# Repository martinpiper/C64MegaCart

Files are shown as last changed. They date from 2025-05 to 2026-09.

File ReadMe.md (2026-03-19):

# C64 Open source cartridges and programmers

## C64MegaCart V4.3

* 2 Megabyte of Flash memory
* Flash can be erased, either the whole memroy or smaller banks, and written by the C64
* When ordering 100 units, each unit should cost about USD 10, excluding shipping and import taxes.
* Can be ordered direct from PCBWay: https://www.pcbway.com/project/shareproject/Commodore_64_MegaCart_V4_3_2MB_eafeb0e4.html
* Code that demonstrates erase and write of a cartridge with some example boot code: https://github.com/martinpiper/C64MegaCart/blob/main/WriteCartTest.a
* Code that demonstrates flash memory erase and write, with cartridge bank kill functionality: https://github.com/martinpiper/C64MegaCart/blob/main/FlashWriteTest.a
* Assembled prg files for this example code are also in this repository.
* Source code for the stdlib includes can be found in this repository: https://github.com/martinpiper/C64Public/tree/master/stdlib

## Cartridge programmer tool

* This is a Raspberry Pi hat
* Software running on the Raspberry Pi can erase, write, and read the flash memory
* Setup video: https://www.youtube.com/watch?v=GBg5k46B5Pw
* Setup instructions: https://github.com/martinpiper/C64MegaCart/blob/main/PiCartTool/ReadMe.md#setup-software-using-gcc
* It multiplexes signals to increase the number of inputs and outputs, allowing the full range of Commodore 64 expansion port signals to be controlled
* It uses MOSFETs to drive higher currents at higher frequencies
* Can be ordered direct from PCBWay: https://www.pcbway.com/project/shareproject/C64_Cartridge_programming_tool_V2_4b4c9cff.html
* Raspberry Pi source code for the programmer is here: https://github.com/martinpiper/C64MegaCart/tree/main/PiCartTool

## About PCB assembly costs

PCBWay have fixed assembly and fabrication setup fees, so when ordering a small number of units these fees increase per unit cost. The best way to reduce the impact of setup fees is to order more units, in bulk.

## Cartridge case for normal sized PCBs

* Case assembly video: https://www.youtube.com/watch?v=x988wTCP7Js
* C64MegaCartNormalCase.FCStd
* Can be used with: FreeCAD_1.0.2-conda-Windows-x86_64-py311
* Top part: https://www.pcbway.com/project/shareproject/Commodore_64_MegaCart_case_Top_f965217a.html
* Bottom part: https://www.pcbway.com/project/shareproject/Commodore_64_MegaCart_case_Bottom_1492af35.html

## Vice 3.1 support

* Vice 3.1 Win32 DirectX build with C64MegaCart support: https://github.com/martinpiper/Vice-3.1-with-C64MegaCart/tree/main/vice-3.1/data
* There are many hooks for the cartridge system, the main source is in: https://github.com/martinpiper/Vice-3.1-with-C64MegaCart/blob/main/vice-3.1/src/c64/cart/c64megacart.c

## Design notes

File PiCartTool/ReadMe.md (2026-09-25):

## Command line arguments

	Long form								Short form	Documentation
	--waitbutton							-b			Waits for the button on the programmer board to be pressed
	--erase									-e			Erases the whole flash memory, first chip only
	--eraseserial							-es			Erases the whole serial EEPROM memory
	--erasechips <num chips>				-ec			Erases the whole flash memory for the number of chips, in parallel
	--eraseblock <number>					-eb			Erases one block of the flash memory using the number value to choose which block. Each flash chip has 256 blocks (banks)
														This depends on the geometry of the flash memory. For example for the chip M29F160FT55N3E2, using 253 will erase the 8KB block at 0x1fa000
	--write <filename>						-w			Writes the file to the flash memory
	--writeserial <filename>				-ws			Writes the file to the serial EEPROM memory
	--writebyte <address> <byte>			-wb			Write a single byte to the address.
	--read <num banks> <filename>			-r			Reads the whole cartridge for the number of banks and writes the data to the filename as a binary file. Only the first slot.
	--readserial <filename>					-rs			Reads the whole serial EEPROM and writes the data to the filename as a binary file. Only the first slot.
	--loop									-l			Loops back to the start of the command line arguments
	--dump <address> <num bytes>			-d			Dumps the flash memory from address for the number of bytes
	--dumpserial <address> <num bytes>		-ds			Dumps the serial EEPROM memory from address for the number of bytes
	--slots <num>							-s			The nunber of slots being used, default is 1, from the front slot to the rear slot

For example, to repeatedly erase and write a file to the cartridge while waiting for the button to be pressed before each erase/write pass:

	--waitbutton --erase --write scrollerbanks.bin --loop

Or for example, to read data from a 256 bank cartridge to a file:

	--read 256 readdata.bin

Or to dump 15 bytes from 0x1fa000, erase the whole block, dump the same bytes to show they are erased, then write a single byte to 0x1fa007, and then dump the bytes to show the single updated byte:

	--dump 0x1fa000 0xf --eraseblock 253 --dump 0x1fa000 0xf  --writebyte 0x1fa007 0x56  --dump 0x1fa000 0xf

## Minimal cartridge boot test

The file CartBoot.bin (assembled from C64MegaCart\CartBoot.a) is a very small minimal cartridge boot which will show a message

	--erase --write CartBoot.bin
	
## Cartridge run EEPROM tester

The file CartBootSimplePRG.bin (assembled from C64MegaCart\CartBootSimplePRG.a) will automatically run an EEPROM tester

	--erase --write CartBootSimplePRG.bin

## Errors

If all LEDs rapidly flash on and off this means there was an error. Usually this happens during erase or write.
The tool will wait for a button to be pressed before executing the next command in the command line.

## Cartridge types

Different cartridges have different requirements for how to write the flash.
C64MegaCart is the default option for this cart tool, so these advanced options are not required, however other cartridges can be configured.
The advanced configuration command line options must be used before the cartridge is accessed.

| Type			| Command line options					| Size (megabytes)	| Typical time to erase and write	|
| ---			| ---									| ---				| ---								|
| 			| 									| 				| Raspberry Pi 5					|
| C64MegaCart	| None needed, use default config		| 2					| 62 seconds						|
| Megabyter		| --cfwcl --cfwdci 4 --crdms 1 --cfwec	| 1					| 44 seconds						|
| Gmod2			| --cfwec --cfct 1						| 0.5 + 2KB EEPROM	| 20 seconds						|
| 			| 									| 				| Raspberry Pi Zero 2W				|
| C64MegaCart	| None needed, use default config		| 2					| 99 seconds						|

Default options are: --cfwch --cfwdci 0 --crdms 0 --cfwnec

### Advanced configuration options

These options alter the timings and other signals expected by different cartridges types.

	Long form			Documentation
	--cfwch				HIROM is used to write to the cartridge flash
	--cfwcl				LOROM is used to write to the cartridge flash
	--cfwdci <number>	Number of times the dot clock signal is toggled during IO/read/write phases
	--crdms <number>	Delay in microseconds
	--cfwec				Use extra clocking for signal generation. This is closer to the standard C64 signal timing, but is slower.
	--cfwnec			No extra clocking for signal generation. This option if faster but some cartridges are unable tolerate the non-standard timings.
	--cfct <number>		0 = M29F160, 1 = M29F040

## Setup software using gcc

Video showing the whole process: https://youtu.be/GBg5k46B5Pw

Video showing the five slot programmer: https://youtu.be/I6Ru7vbInTw

This software uses: https://github.com/WiringPi/WiringPi

	sudo apt install git
	git clone https://github.com/WiringPi/WiringPi.git

Or if that repository disappears:

	git clone https://github.com/martinpiper/WiringPi.git

Then compile with:

	cd WiringPi
	./build
	cd ..

To compile the programmer tool:

	git clone https://github.com/martinpiper/C64MegaCart.git
	cd C64MegaCart/PiCartTool
	gcc main.cpp Hardware.cpp CartridgePort.cpp ProgrammerHardware.cpp CartridgeHardware.cpp -o PiCartTool -lstdc++ -lwiringPi -O3

You can then use this command to test erase and write the cartridge:

	./PiCartTool --waitbutton --erase --write scrollerbanks.bin --loop

## Setup software using Microsoft Dev Studio

Usually gcc builds will work fine, this is more for remote development and debugging.

MSDev->Tools->Options->Cross Platform->Connection Manager
Default Raspberry Pi login: user:pi password:raspberry
Configuration Manager: ARM64

	cd ~/projects/PiCartTool/bin/ARM64/Release/
	time ./PiCartTool.out --erase --write ../../../scrollerbanks.bin
	diff -q ../../../scrollerbanks.bin ../../../readdata.bin
	cmp -l ../../../scrollerbanks.bin ../../../readdata.bin | mawk 'function oct2dec(oct,     dec) {for (i = 1; i <= length(oct); i++) {dec *= 8; dec += substr(oct, i, 1)}; return dec} {printf "%08X %02X %02X\n", $1-1, oct2dec($2), oct2dec($3)}'

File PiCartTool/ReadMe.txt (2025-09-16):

## Command line arguments

	Long form				Short form	Documentation
	--waitbutton			-b			Waits for the button on the programmer board to be presse
	--erase					-e			Erases the whole flash memor
	--eraseblock <number>	-eb			Erases one block of the flash memory using the number value to choose which block.
										This depends on the geometry of the flash memory. For example for the chip M29F160FT55N3E2, using 253 will erase the 8KB block at $1fa000.
	--write <filename>		-w			Writes the file to the flash memor
	--read <filename>		-r			Reads the whole cartridge and writes the data to the filename as a binary fil
	--loop					-l			Loops back to the start of the command line arguments

For example, to repeatedly erase and write a file to the cartridge while waiting for the button to be poressed before each erase/write pass:

	--waitbutton --erase --write scrollerbanks.bin --loop

## Setup software using gcc

This uses: https://github.com/WiringPi/WiringPi

sudo apt install git
git clone https://github.com/WiringPi/WiringPi.git
Or if that repository disappears: git clone https://github.com/martinpiper/WiringPi.git
cd WiringPi
./build
cd ..

git clone https://github.com/martinpiper/C64MegaCart.git
cd C64MegaCart/PiCartTool
gcc main.cpp -o PiCartTool -lwiringPi -O3

You can then use this command to test erase and write the cartridge: ./PiCartTool --waitbutton --erase --write scrollerbanks.bin --loop

## Setup software using Microsoft Dev Studio

Usually gcc builds will work fine, this is more for remote development and debugging.

MSDev->Tools->Options->Cross Platform->Connection Manager
Default Raspberry Pi login: user:pi password:raspberry

cd ~/projects/PiCartTool/bin/ARM/Release/
time ./PiCartTool.out
diff -q ../../../scrollerbanks.bin ../../../readdata.bin
cmp -l ../../../scrollerbanks.bin ../../../readdata.bin | mawk 'function oct2dec(oct,     dec) {for (i = 1; i <= length(oct); i++) {dec *= 8; dec += substr(oct, i, 1)}; return dec} {printf "%08X %02X %02X\n", $1-1, oct2dec($2), oct2dec($3)}'

RaspberryPi5 erase 2MB + write 2MB + read/verify 2MB cycle = 1m17s
The PiZero took about 2m for the same erase/write
The full read/verify on its own takes 17s
It's probably not needed since the write uses a read to verify the write has completed.

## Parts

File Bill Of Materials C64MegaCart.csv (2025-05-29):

Category | Quantity | References | Value | Stock Code | Description | Group Layer | PCB Package | Placed
Capacitors | 1 | C1 | CL05B104KO5NNNC | https://www.mouser.sg/ProductDetail/Samsung-Electro-Mechanics/CL05B104KO5NNNC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 | Samsung Electro-Mechanics CL05B104KO5NNNC 100nF Multilayer Ceramic Capacitor MLCC 16V dc +/-10% Tolerance SMD |  | CAPC1005X55N | Top Copper
Integrated Circuits | 1 | U1 | M29F160FT55N3E2 | https://www.mouser.sg/ProductDetail/Alliance-Memory/M29F160FT55N3E2?qs=vmHwEFxEFR%252BPKObcaS0Aqw%3D%3D | NOR Flash |  | SOP50P2000X120-48N | Top Copper
Integrated Circuits | 1 | U259 | 74273 | https://www.mouser.sg/ProductDetail/Texas-Instruments/SN74LS273NSR?qs=SL3LIuy2dWxsq%2FCTeVMKZg%3D%3D | Octal D-Type Positive-Edge-Triggered Flip-Flops With Clear | Video | SOIC127P780X200-20N-CAP | Top Copper
Miscellaneous | 1 | 7R | 74S139 | https://www.mouser.sg/ProductDetail/Texas-Instruments/SN74LS139ADR?qs=SL3LIuy2dWwpYzaAOf%252BnlA%3D%3D | Dual 2-Line to 4-Line Decoders/Demultiplexers | Video | SOIC127P600X175-16N-CAP | Top Copper

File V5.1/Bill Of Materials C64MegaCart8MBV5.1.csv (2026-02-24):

Category | Quantity | References | Value | Stock Code | Description | Group Layer | PCB Package | Supplier | Placed
Capacitors | 4 | C1,C2,C3,C4 | CL05B104KO5NNNC | https://www.mouser.sg/ProductDetail/Samsung-Electro-Mechanics/CL05B104KO5NNNC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 | Samsung Electro-Mechanics CL05B104KO5NNNC 100nF Multilayer Ceramic Capacitor MLCC 16V dc +/-10% Tolerance SMD |  | CAPC1005X55N |  | Top Copper
Integrated Circuits | 4 | U1,U6,U7,U8 | M29F160FT55N3E2 | https://www.mouser.sg/ProductDetail/Alliance-Memory/M29F160FT55N3E2?qs=vmHwEFxEFR%252BPKObcaS0Aqw%3D%3D | NOR Flash |  | SOP50P2000X120-48N |  | Top Copper
Integrated Circuits | 2 | U2,U3 | 74273 | https://www.mouser.sg/ProductDetail/Texas-Instruments/SN74LS273NSR?qs=SL3LIuy2dWxsq%2FCTeVMKZg%3D%3D | Octal D-Type Positive-Edge-Triggered Flip-Flops With Clear |  | SOIC127P780X200-20N-CAP | https://www.mouser.sg/ProductDetail/Mill-Max/110-43-320-41-801000?qs=RC2ne4458IKe5rHuueYA%2FA%3D%3D | Top Copper
Integrated Circuits | 3 | U4,U5,U9 | 74S139 | https://www.mouser.sg/ProductDetail/Texas-Instruments/SN74LS139ADR?qs=SL3LIuy2dWwpYzaAOf%252BnlA%3D%3D | Dual 2-Line to 4-Line Decoders/Demultiplexers |  | SOIC127P600X175-16N-CAP | https://www.mouser.sg/ProductDetail/Mill-Max/110-13-316-41-801000?qs=WZeyYeqMOWd122xzWNZKKg%3D%3D | Top Copper
Miscellaneous | 1 | J1 | CONN-DIL44 |  | 0.1in pitch DIL connector strip |  | CONN-DIL44 |  | Top Copper

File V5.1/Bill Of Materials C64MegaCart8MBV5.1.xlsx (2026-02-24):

Category | Quantity | References | Value | Stock Code | Description | PCB Package | Placed
Capacitors | 4 | C1,C2,C3,C4 | CL05B104KO5NNNC | https://www.mouser.sg/ProductDetail/Samsung-Electro-Mechanics/CL05B104KO5NNNC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 | Samsung Electro-Mechanics CL05B104KO5NNNC 100nF Multilayer Ceramic Capacitor MLCC 16V dc +/-10% Tolerance SMD | CAPC1005X55N | Top Copper
Integrated Circuits | 4 | U1,U6,U7,U8 | M29F160FT55N3E2 | https://www.mouser.sg/ProductDetail/Alliance-Memory/M29F160FT55N3E2?qs=vmHwEFxEFR%252BPKObcaS0Aqw%3D%3D | NOR Flash | SOP50P2000X120-48N | Top Copper
Integrated Circuits | 2 | U2,U3 | SN74LS273NSR | https://www.mouser.sg/ProductDetail/Texas-Instruments/SN74LS273NSR?qs=SL3LIuy2dWxsq%2FCTeVMKZg%3D%3D | Octal D-Type Positive-Edge-Triggered Flip-Flops With Clear | SOIC127P780X200-20N-CAP | Top Copper
Integrated Circuits | 3 | U4,U5,U9 | SN74LS139ADR | https://www.mouser.sg/ProductDetail/Texas-Instruments/SN74LS139ADR?qs=SL3LIuy2dWwpYzaAOf%252BnlA%3D%3D | Dual 2-Line to 4-Line Decoders/Demultiplexers | SOIC127P600X175-16N-CAP | Top Copper
Capacitors | 5 | One 100nF (0.1uF) capacitor for SMT ICs marked with extra SDC near pin 1 | CL05B104KO5NNNC | https://www.mouser.sg/ProductDetail/Samsung-Electro-Mechanics/CL05B104KO5NNNC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 | Decoupling capacitors for each SDC component | All with suffix -CAP | Top Copper

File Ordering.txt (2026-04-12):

When ordering please include your delivery name and address.

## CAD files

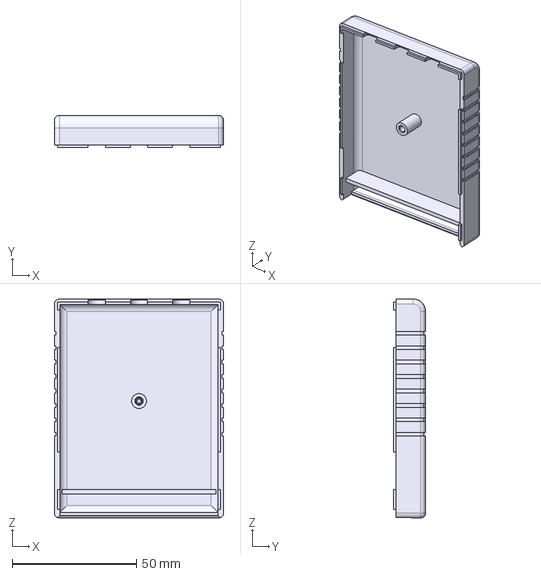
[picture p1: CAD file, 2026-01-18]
C64MegaCartNormalCase-Assemblytop001.step
68.0 x 13.0 x 88.0 mm

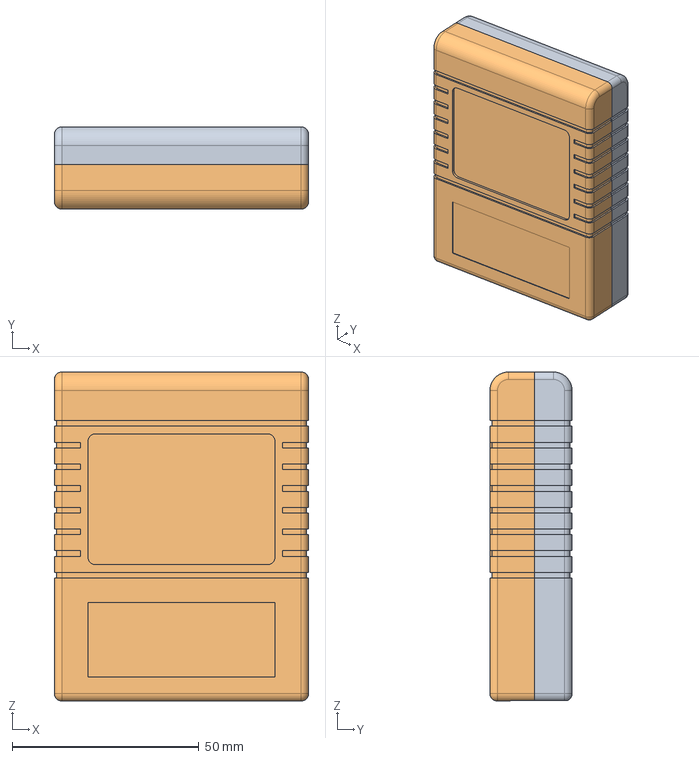
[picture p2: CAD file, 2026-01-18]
C64MegaCartNormalCase.FCStd
68.0 x 22.0 x 88.0 mm
bottom
top

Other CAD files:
C64MegaCartNormalCase-Assemblybottom001.step

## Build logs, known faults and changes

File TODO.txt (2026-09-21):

* Currently there is one 8-bit latch for the whole bank register, in IO1
	At power on, after _RESET, _GAME is high and _EXROM is low, giving 8KB ROML based cartridge
	Adding another register in IO2 will allow the _GAME and _EXROM lines to be controlled
	* It would be possible to set _GAME low and have _EXROM high (from IO2 register) only when A15 is set and R_W is low and when RGAME (IO2 register control GAME bit) is high and PHI2 is high
		This would give ultimax mode and allow writes to $e000-$ffff to control the address (plus IO1 bank register) and data lines lines to the flash _WE (_RWE i.e. ROM _WE) signal
		_ROMH would go straight to _RWE
	* Using M29F160FT55N3E2
	Page 25 Command write signals
		>> Note _OE must be high during commands/programming
		>> The address inputs are latched by the command interface on the falling edge of CE# or WE#, whichever occurs last.
		>> The data I/Os are latched by the command interface on the rising edge of CE# or WE#, whichever occurs first.
	Page 31 programm command, chip erase, block erase etc
	Page 37 https://www.mouser.sg/datasheet/2/12/M29FxxFT_FB-2999423.pdf says "Bus Read operations from any address always read the Status Register during Program and Erase operations."
	Page 47 Documents VID voltage 11.5V-12.5V
	Page 53 Gives program and erase timings, in seconds!
		Chip erase typical 25 seconds, max 120 seconds!!
		Block erase typcial 0.8 seconds, max 6 seconds!!
	>> Note: During Program operations the Data Polling Bit outputs the complement of the bit being programmed to DQ7. After successful completion of the Program operation the
memory returns to Read mode and Bus Read operations from the address just programmed output DQ7, not its complement.

* Option to have _GAME and _EXROM dynamically low only for CPU read access, giving VIC the RAM under the cartridge
	And only _GAME for $e000 option, giving ROM replacement as an option

* C64 flash write option (_RWE), with writes to $e000-$ffff activing as flash write when in ultimax mode
	Retain the pad/hole with _RWE and RYBY, it might be useful for the external programmer...

* Real cartridge data:
	Ensure Scroller multidirection code is built in gmod2 mode
	C:\Users\marti\Downloads\SDLVICE-3.7.1-win64-r43772\SDLVICE-3.7.1-win64-r43772\cartconv.exe -f c:\work\c64\Scroller\Scroller.crt
	C:\Users\marti\Downloads\SDLVICE-3.7.1-win64-r43772\SDLVICE-3.7.1-win64-r43772\cartconv.exe -i c:\work\c64\Scroller\Scroller.crt -o c:\temp\scrollerbanks.bin

* CartTool V2: Perhaps have the _IO/_ROM outputs (faked from the C64) default to 1 on powerup?

* Edge conector should not have any power plane near the pads.

* Maybe a Python flask based website?
	Which can call the relevant PiCartTool command line options?
	>> https://flask.palletsprojects.com/en/stable/installation/#python-version
	>> On Windows:
		pip install Flask
	>> On RaspberryPi5:
		cd ~/projects/PiCartTool
		python3 -m venv .venv
		. .venv/bin/activate
		pip install Flask
	>> Then: flask --app Programmer run --host=0.0.0.0
	>> http://127.0.0.1:5000
	>> http://raspberrypi5:5000/

* The middle hole might need to rest on the 6mm post with enough room to avoid the screw thread and with suitable gap between case top and bottom parts.

* Maybe a linear read byte mode, normally direct memory to low/high ROM uses the memory address and this should remain. However if reading a specific value in $dexx or $dfxx could return a linearly address byte this would help fast decompression or scrolling or video etc...
	Perhaps a bank of counters can be set by writing to specific $dexx/$dfxx, then each specific $dexx/dfxx read can advance that counter by one on the negative edge of _READ, giving enough time for a stable value to be read from the memory? Or even incremented on the _READ positive edge, assuming the read value can be held for long enough...
	It may also be possible to have more than one counter bank set and selected and advanced by a read from different IO space addresses... Giving multiple linear multiplexed reads...

* LEDs WP7113SURDK
	LED forward voltage resistor calculator: https://www.digikey.com/en/resources/conversion-calculators/conversion-calculator-led-series-resistor

* Resistor sizes

* Check level shifter resistor placement on 5 slot board with respect to the level shifter

* PiCartTool when reporting an error with flashing LEDs, there is no need to enable/disable power

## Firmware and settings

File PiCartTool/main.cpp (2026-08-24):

#include <stdio.h>
#include <stdlib.h>
#include <string.h>
#include <wiringPi.h>
#include <atomic>
#include <algorithm>
#include <chrono>
#include <string>
#include "Hardware.h"
#include "CartridgePort.h"
#include "CartridgeHardware.h"
#include "ProgrammerHardware.h"

int main(int argc, char** argv)
{
	unsigned char bankData[8192];
	FILE* fp;

	auto start = std::chrono::steady_clock::now();

	HardwareInit();
	InitCartTool();

	int argPos = 1;
	while (argPos < argc)
	{
		// Parse cartridge options
		if (strcasecmp(argv[argPos], "--cfwch") == 0)
		{
			argPos++;
			flashWriteCommandIsHiROM = true;
			continue;
		}
		if (strcasecmp(argv[argPos], "--cfwcl") == 0)
		{
			argPos++;
			flashWriteCommandIsHiROM = false;
			continue;
		}
		if (strcasecmp(argv[argPos], "--cfwdci") == 0)
		{
			argPos++;
			flashWriteToggleDotClockIterations = std::stoi(argv[argPos], nullptr, 0);
			argPos++;
			continue;
		}
		if (strcasecmp(argv[argPos], "--crdms") == 0)
		{
			argPos++;
			RegisterDelayMicroSeconds = std::stoi(argv[argPos], nullptr, 0);
			argPos++;
			continue;
		}
		if (strcasecmp(argv[argPos], "--cfwec") == 0)
		{
			argPos++;
			flashWriteCommandExtraClocking = true;
			continue;
		}
		if (strcasecmp(argv[argPos], "--cfwnec") == 0)
		{
			argPos++;
			flashWriteCommandExtraClocking = false;
			continue;
		}
		if (strcasecmp(argv[argPos], "--cfct") == 0)
		{
			argPos++;
			flashChipType = (FlashChipType) std::stoi(argv[argPos], nullptr, 0);
			argPos++;
			continue;
		}

		HardwareInit();
		InitCartTool();

		InterfaceControl::ClearRelay1();
		InterfaceControl::UpdateLatch();

		if (strcasecmp(argv[argPos], "--waitbutton") == 0 || strcasecmp(argv[argPos], "-b") == 0)
		{
			argPos++;
			printf("Waiting for button...\n");
			while (digitalRead(24) == HIGH)
			{
				delay(100);
				AlternateLED2();
			}
			while (digitalRead(24) == LOW)
			{
				delay(100);
				AlternateLED2();
			}
			InterfaceControl::ClearLED2();
			InterfaceControl::UpdateLatch();
			continue;
		}

		// Default to the first slot...
		InterfaceControl::SetActiveSlot(0);
		InterfaceControl::UpdateLatch();

		// Enable power
		InterfaceControl::SetRelay1();
		InterfaceControl::UpdateLatch();
		delay(100); // A small delay to allow the relay to physically switch on the cartridge power

		ResetCartridge();

		if (strcasecmp(argv[argPos], "--erasechips") == 0 || strcasecmp(argv[argPos], "-ec") == 0)
		{
			argPos++;
			int numChips = std::stoi(argv[argPos], nullptr, 0);
			argPos++;

			InterfaceControl::SetLED0();
			InterfaceControl::UpdateLatch();

			for (int chip = 0; chip < numChips; chip++)
			{
				printf("Erasing chip %d\n" , chip);
				SetDataIO2(chip);
				SendChipCommandErase();
			}

			for (int slot = 0; slot < activeSlots; slot++)
			{
				InterfaceControl::SetActiveSlot(slot);

				for (int chip = 0; chip < numChips; chip++)
				{
					printf("Waiting for chip %d\n", chip);
					SetDataIO2(chip);
					WaitForStatusRegisterEqual(0xff);
				}

				SetDataIO2(0);
			}

			InterfaceControl::ClearLED0();
			InterfaceControl::UpdateLatch();

			continue;
		}

		if (strcasecmp(argv[argPos], "--erase") == 0 || strcasecmp(argv[argPos], "-e") == 0)
		{
			argPos++;

			InterfaceControl::SetLED0();
			InterfaceControl::UpdateLatch();

			printf("Erasing...\n");
			SendChipCommandErase();

			for (int slot = 0; slot < activeSlots; slot++)
			{
				InterfaceControl::SetActiveSlot(slot);
				WaitForStatusRegisterEqual(0xff);
			}

			InterfaceControl::ClearLED0();
			InterfaceControl::UpdateLatch();

			continue;
		}

		if (strcasecmp(argv[argPos], "--write") == 0 || strcasecmp(argv[argPos], "-w") == 0)
		{
			argPos++;

			InterfaceControl::SetLED1();
			InterfaceControl::UpdateLatch();

			printf("Writing...\n");
			// Write some data to the flash, using the program command sequence
			fp = fopen(argv[argPos], "rb");
			argPos++;
			if (fp == 0)
			{
				printf("Error reading input file\n");
				continue;
			}

			bool gotError = false;
			int bank = 0;
			while (!feof(fp))
			{
				size_t numBytes = fread(bankData, sizeof(bankData[0]), sizeof(bankData), fp);
				if (gotError)
				{
					break;
				}
				if (numBytes == 0)
				{
					break;
				}
				printf("Got bytes %d for bank %d\n", numBytes, bank);

				// Set the bank register
				SetDataIO1(0, bank);
				SetDataIO2(bank >> 8);

				for (int address = 0; address < (int)sizeof(bankData); address++)
				{
					if (gotError)
					{
						break;
					}

					if ((address & 0xff) == 0)
					{
						printf(".");
						fflush(stdout);
					}

					// If it's going to be the same as an erased flash byte then skip it :)
					if (bankData[address] == 0xff)
					{
						continue;
					}

					// Program commands
					SendChipCommandProgram();

					// Program command4 (the actual byte)
					DataLatchOut::SetAddress(address);
					int theWriteValue = bankData[address];
					DataLatchOut::SetData(theWriteValue);

					PerformCartridgeWriteCycle();

					for (int slot = 0; slot < activeSlots; slot++)
					{
						InterfaceControl::SetActiveSlot(slot);

						int statusRegister = 0;
						int iterations = 0;
						do
						{
							if (gotError)
							{
								break;
							}

							C64Control::SetLowROM();
							C64Control::UpdateLatch();
							//				delay(0);	// Certainly more than the 20ns for a bus read
							if (iterations > 50)
							{
								delayMicroseconds(1);
							}
							statusRegister = GetInputByte();
							C64Control::ClearLowROM();
							C64Control::UpdateLatch();
							if (iterations++ > 100)
							{
								printf("There seems to be a problem verifying the byte at address $%04x slot %d\n", address, slot+1);
								ReportCartridgeError();
								gotError = true;
								break;
							}
						} while (statusRegister != theWriteValue);
					}
					InterfaceControl::SetActiveSlot(0);
				}

				if (gotError)
				{
					break;
				}

				printf("\nBank done\n");
				bank++;
			}

			InterfaceControl::ClearLED1();
			InterfaceControl::UpdateLatch();

			continue;
		}

		if (strcasecmp(argv[argPos], "--eraseblock") == 0 || strcasecmp(argv[argPos], "-eb") == 0)
		{
			argPos++;

			InterfaceControl::SetLED0();
			InterfaceControl::UpdateLatch();

			int bank = std::stoi(argv[argPos], nullptr, 0);
			argPos++;
			printf("Erasing one block at bank %d\n" , bank);
			// Write some data to the flash, using the erase block command sequence
			DataLatchOut::SetAddress(0);
			SetDataIO1(0, bank);
			SetDataIO2(bank >> 8);

			SendChipCommandBlockErase();

			for (int slot = 0; slot < activeSlots; slot++)
			{
				InterfaceControl::SetActiveSlot(slot);
				WaitForStatusRegisterEqual(0xff);
			}

			InterfaceControl::SetActiveSlot(0);

			InterfaceControl::ClearLED0();
			InterfaceControl::UpdateLatch();

			continue;
		}

		if (strcasecmp(argv[argPos], "--read") == 0 || strcasecmp(argv[argPos], "-r") == 0)
		{
			argPos++;
			int numBanks = std::stoi(argv[argPos], nullptr, 0);
			argPos++;
			InterfaceControl::SetLED2();
			InterfaceControl::UpdateLatch();

			printf("Reading...\n");
			int maxDelayNeeded = 0;
			fp = fopen(argv[argPos], "wb");
			argPos++;

			for (int bank = 0; bank < numBanks; bank++)
			{
				printf("Bank %d\n", bank);
				SetDataIO1(0, bank);
				SetDataIO2(bank >> 8);

				for (int address = 0; address < (int)sizeof(bankData); address++)
				{
					/*
								if ((address & 0x3ff) == 0)
								{
									printf(".");
									fflush(stdout);
								}
					*/

					DataLatchOut::SetAddress(address);
					C64Control::ClearFlashWrite();
					C64Control::ClearDataLatchOut();

					// Tries two reads without any delay, then progressively increases the delay until we get two reads that are the same
					int gotPrevious = -1;
					int gotNow = -2;
					int progressiveDelay = 0;
					while (gotPrevious != gotNow)
					{
						gotPrevious = gotNow;

						C64Control::SetLowROM();
						C64Control::UpdateLatch();
						if (progressiveDelay >= 2)
						{
							delayMicroseconds(progressiveDelay / 2);
							maxDelayNeeded = std::max(maxDelayNeeded, progressiveDelay / 2);
						}
						gotNow = (unsigned char)GetInputByte();
						C64Control::ClearLowROM();
						C64Control::UpdateLatch();
						progressiveDelay++;
					}
					bankData[address] = (unsigned char)gotNow;
				}

				fwrite(bankData, sizeof(bankData[0]), sizeof(bankData), fp);
				//		printf("\nBank done\n");
			}
			fclose(fp);
			printf("maxDelayNeeded = %d\n", maxDelayNeeded);

			InterfaceControl::ClearLED2();
			InterfaceControl::UpdateLatch();

			continue;
		}

		if (strcasecmp(argv[argPos], "--loop") == 0 || strcasecmp(argv[argPos], "-l") == 0)
		{
			argPos = 1;
			continue;
		}


		if (strcasecmp(argv[argPos], "--dump") == 0 || strcasecmp(argv[argPos], "-d") == 0)
		{
			argPos++;
			int address = std::stoi(argv[argPos], nullptr, 0);
			argPos++;
			int numBytes = std::stoi(argv[argPos], nullptr, 0);
			argPos++;
			InterfaceControl::SetLED2();
			InterfaceControl::UpdateLatch();

			int maxDelayNeeded = 0;
			for (int slot = 0; slot < activeSlots; slot++)
			{
				printf("Dumping slot %d\n", slot + 1);
				InterfaceControl::SetActiveSlot(slot);

				for (int bytes = 0; bytes < numBytes; bytes++)
				{
					int bank = (address + bytes) / sizeof(bankData);
					SetDataIO1(0, bank);
					SetDataIO2(bank >> 8);

					DataLatchOut::SetAddress(address + bytes);
					C64Control::ClearFlashWrite();
					C64Control::ClearDataLatchOut();

					// Tries two reads without any delay, then progressively increases the delay until we get two reads that are the same
					int gotPrevious = -1;
					int gotNow = -2;
					int progressiveDelay = 0;
					while (gotPrevious != gotNow)
					{
						gotPrevious = gotNow;

						C64Control::SetLowROM();
						C64Control::UpdateLatch();
						if (progressiveDelay >= 2)
						{
							delayMicroseconds(progressiveDelay / 2);
							maxDelayNeeded = std::max(maxDelayNeeded, progressiveDelay / 2);
						}
						gotNow = (unsigned char)GetInputByte();
						C64Control::ClearLowROM();
						C64Control::UpdateLatch();
						progressiveDelay++;
					}

					printf(" %02x ", gotNow);
					fflush(stdout);
				}
				printf("\n");
			}

			printf("maxDelayNeeded = %d\n", maxDelayNeeded);

			InterfaceControl::ClearLED2();
			InterfaceControl::UpdateLatch();

			continue;
		}

		if (strcasecmp(argv[argPos], "--dumpserial") == 0 || strcasecmp(argv[argPos], "-ds") == 0)
		{
			argPos++;
			int address = std::stoi(argv[argPos], nullptr, 0);
			argPos++;
			int numBytes = std::stoi(argv[argPos], nullptr, 0);
			argPos++;
			InterfaceControl::SetLED2();
			InterfaceControl::UpdateLatch();

			for (int slot = 0; slot < activeSlots; slot++)
			{
				printf("Dumping serial slot %d\n", slot + 1);
				InterfaceControl::SetActiveSlot(slot);

				SerialEEPROM_Init();

				// https://www.st.com/resource/en/datasheet/m93c76-r.pdf
				/*
				Chip: m93C86
				Page 8
				Each instruction is preceded by a rising edge on Chip Select Input (S) with Serial Clock (C) being held low.
					
				A start bit, which is the first '1' read on Serial Data Input (D) during the rising edge of Serial Clock (C).
					
				Two op-code bits, read on Serial Data Input (D) during the rising edge of Serial Clock (C). (Some
				instructions also use the first two bits of the address to define the op - code)
					
				The address bits of the byte or word that is to be accessed.
				For the M93C86, the address is made up of 10 bits for the x16 organization or 11 bits for the x8 organization
				Page 9 for M93C86
				READ Read Data from Memory 1 10 A10-A0 Q7-Q0
				*/


				// Reset instruction
				SerialEEPROM_Reset();
				// Start bit
				SerialEEPROM_SendBit(1);

				// Read command
				SerialEEPROM_SendBit(1);
				SerialEEPROM_SendBit(0);

				SerialEEPROM_SendAddress(address);

				// Skip dummy bit...
				SerialEEPROM_DoClock();

				for (int i = 0; i < numBytes; i++)
				{
					int byte = SerialEEPROM_ReadByte();
					printf("%02x ", byte);
					fflush(stdout);
				}

				printf("\n");
			}

			InterfaceControl::ClearLED2();
			InterfaceControl::UpdateLatch();

			continue;
		}

		if (strcasecmp(argv[argPos], "--readserial") == 0 || strcasecmp(argv[argPos], "-rs") == 0)
		{
			argPos++;
			fp = fopen(argv[argPos], "wb");
			argPos++;

			InterfaceControl::SetLED2();
			InterfaceControl::UpdateLatch();

			printf("Reading serial\n");

			SerialEEPROM_Init();

			// Reset instruction
			SerialEEPROM_Reset();
			// Start bit
			SerialEEPROM_SendBit(1);

			// Read command
			SerialEEPROM_SendBit(1);
			SerialEEPROM_SendBit(0);

			SerialEEPROM_SendAddress(0);

			// Skip dummy bit...
			SerialEEPROM_DoClock();

			for (int i = 0; i < (1<<kSerialEEPROM_AddressBits); i++)
			{
				if ((i & 0xff) == 0)
				{
					printf(".");
					fflush(stdout);
				}

				int byte = SerialEEPROM_ReadByte();
				fputc(byte, fp);
				byte = SerialEEPROM_ReadByte();
				fputc(byte, fp);
			}

			fclose(fp);
			printf("\nDone reading serial\n");

			InterfaceControl::ClearLED2();
			InterfaceControl::UpdateLatch();

			continue;
		}

		if (strcasecmp(argv[argPos], "--writebyte") == 0 || strcasecmp(argv[argPos], "-wb") == 0)
		{
			argPos++;
			int address = std::stoi(argv[argPos], nullptr, 0);
			argPos++;
			int byte = std::stoi(argv[argPos], nullptr, 0);
			argPos++;
			InterfaceControl::SetLED2();
			InterfaceControl::UpdateLatch();

			printf("Writing single byte $%x at $%x...\n" , byte , address);
			int maxDelayNeeded = 0;

			int bank = address / sizeof(bankData);
			SetDataIO1(0, bank);
			SetDataIO2(bank >> 8);

			SendChipCommandProgram();

			DataLatchOut::SetAddress(address);
			DataLatchOut::SetData(byte);

			PerformCartridgeWriteCycle();

			C64Control::SetRead();
			C64Control::ClearLowROM();
			C64Control::ClearHighROM();
			C64Control::UpdateLatch();

			for (int slot = 0; slot < activeSlots; slot++)
			{
				InterfaceControl::SetActiveSlot(slot);

				// Tries two reads without any delay, then progressively increases the delay until we get two reads that are the same
				int gotPrevious = -1;
				int gotNow = -2;
				int progressiveDelay = 0;
				while ((gotPrevious != gotNow) && (gotNow != byte))
				{
					gotPrevious = gotNow;

					C64Control::SetLowROM();
					C64Control::UpdateLatch();
					if (progressiveDelay >= 2)
					{
						delayMicroseconds(progressiveDelay / 2);
						maxDelayNeeded = std::max(maxDelayNeeded, progressiveDelay / 2);
					}
					if (progressiveDelay > 20)
					{
						printf("Error the read delay is too long, perhaps the flash write is failing...\n");
						break;
					}
					gotNow = (unsigned char)GetInputByte();
					C64Control::ClearLowROM();
					C64Control::UpdateLatch();
					progressiveDelay++;
				}

				InterfaceControl::SetActiveSlot(0);
			}

			printf("\n");
			printf("maxDelayNeeded = %d\n", maxDelayNeeded);

			InterfaceControl::ClearLED2();
			InterfaceControl::UpdateLatch();

			continue;
		}

		if (strcasecmp(argv[argPos], "--slots") == 0 || strcasecmp(argv[argPos], "-s") == 0)
		{
			argPos++;
			activeSlots = std::stoi(argv[argPos], nullptr, 0);
			argPos++;

			continue;
		}

		if (strcasecmp(argv[argPos], "--eraseserial") == 0 || strcasecmp(argv[argPos], "-es") == 0)
		{
			bool gotError = false;
			argPos++;

			InterfaceControl::SetLED2();
			InterfaceControl::UpdateLatch();

			InterfaceControl::SetActiveSlot(0);
			InterfaceControl::UpdateLatch();

			SerialEEPROM_Init();

			SerialEEPROM_SendWriteEnable();

			// Reset instruction
			SerialEEPROM_Reset();
			// Start bit
			SerialEEPROM_SendBit(1);

			// Erase command
			SerialEEPROM_SendBit(0);
			SerialEEPROM_SendBit(0);

			// Send expected address...
			SerialEEPROM_SendBit(1);
			SerialEEPROM_SendBit(0);
			for (int i = 0; i < kSerialEEPROM_AddressBits - 2; i++)
			{
				SerialEEPROM_SendBit(0);
			}

			SerialEEPROM_WaitForReadyAllslots(gotError);

			printf("\n");

			InterfaceControl::ClearLED2();
			InterfaceControl::UpdateLatch();

			continue;
		}


		if (strcasecmp(argv[argPos], "--writeserial") == 0 || strcasecmp(argv[argPos], "-ws") == 0)
		{
			bool gotError = false;
			argPos++;

			InterfaceControl::SetLED1();
			InterfaceControl::UpdateLatch();

			printf("Writing serial...\n");

			// Write some data to the flash, using the program command sequence
			fp = fopen(argv[argPos], "rb");
			argPos++;
			if (fp == 0)
			{
				printf("Error reading input file\n");
				continue;
			}

			size_t numBytes = fread(bankData, sizeof(bankData[0]), sizeof(bankData), fp);
			fclose(fp);

			if (numBytes == 0)
			{
				break;
			}

			printf("Got bytes %d\n", numBytes);

			InterfaceControl::SetActiveSlot(0);
			InterfaceControl::UpdateLatch();

			SerialEEPROM_Init();

			SerialEEPROM_SendWriteEnable();

			for (int address = 0; address < (int)numBytes; address += 2)
			{
				if ((address & 0xff) == 0)
				{
					printf(".");
					fflush(stdout);
				}

				// Reset instruction
				SerialEEPROM_Reset();
				// Start bit
				SerialEEPROM_SendBit(1);

				// Write command
				SerialEEPROM_SendBit(0);
				SerialEEPROM_SendBit(1);

				SerialEEPROM_SendAddress(address >> 1);

				SerialEEPROM_SendByte(bankData[address]);
				SerialEEPROM_SendByte(bankData[address+1]);

				SerialEEPROM_WaitForReadyAllslots(gotError);

				if (gotError)
				{
					break;
				}
			}

			printf("\nWrite serial done\n");

			InterfaceControl::SetActiveSlot(0);
			InterfaceControl::UpdateLatch();

			InterfaceControl::ClearLED1();
			InterfaceControl::UpdateLatch();

			continue;
		}

		printf("Unknown argument: %s\n", argv[argPos]);
		argPos++;
	}

	// Final power off
	InterfaceControl::ClearRelay1();
	InterfaceControl::UpdateLatch();

	auto end = std::chrono::steady_clock::now();

	// Calculate elapsed time as a double in seconds
	std::chrono::duration<double> elapsed = end - start;

	printf("Elapsed time: %f seconds\n" , elapsed.count());
	return 0;
}

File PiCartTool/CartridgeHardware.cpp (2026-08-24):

// Page numbers reference "For M29F160FT55N3E2 - M29FxxFT_FB-2999423.pdf"
#include <stdio.h>
#include <wiringPi.h>
#include "Hardware.h"
#include "CartridgePort.h"
#include "CartridgeHardware.h"
#include "ProgrammerHardware.h"

// Some cartridges need a slightly longer delay for accurate writes
int RegisterDelayMicroSeconds = 0;
// Some cartridges need extra clocking of output signals to simulate slightly staggered bus signals from the C64.
// This is slower but more accurate.
bool flashWriteCommandExtraClocking = false;

FlashChipType flashChipType = M29F160;

void ResetCartridge(void)
{
	// Reset the cartridge before any operations
	printf("Before reset\n");
	ShowCartridgeState();
	InterfaceControl::SetReset();
	InterfaceControl::UpdateLatch();
	printf("During reset\n");
	ShowCartridgeState();
	InterfaceControl::ClearReset();
	InterfaceControl::UpdateLatch();
	printf("After reset\n");
	ShowCartridgeState();
	ClearCartridgeIO();
	printf("After IO clear\n");
	ShowCartridgeState();
}

void ClearCartridgeIO(void)
{
	// Clear any cartridge IO, to common values
	for (int i = 0; i < 256; i++)
	{
		SetDataIO1(i, 0);
		SetDataIO2(i, 0);
	}
}

void SendChipCommand(int address, int data)
{
	DataLatchOut::SetAddress(address);
	DataLatchOut::SetData(data);

	if (flashWriteCommandExtraClocking)
	{
		C64Control::SetDataLatchOut();
		C64Control::UpdateLatch();
		C64Control::SetWrite();
		C64Control::UpdateLatch();
		C64Control::SetFlashWrite();
		C64Control::UpdateLatch();
		C64Control::ToggleDotClock();
		safeDelayMicroseconds(RegisterDelayMicroSeconds);
		C64Control::ClearFlashWrite();
		C64Control::UpdateLatch();
		C64Control::SetRead();
		C64Control::UpdateLatch();
		C64Control::ToggleDotClock();
		// Will clear flash write a little before the data output, this might generate a momentary logic contention state
			// TODO: See if both the write and the latch out can be cleared at the same time
		C64Control::ClearDataLatchOut();
		C64Control::UpdateLatch();
	}
	else
	{
		C64Control::SetDataLatchOut();
		C64Control::SetFlashWrite();
		C64Control::UpdateLatch();
		C64Control::ToggleDotClock();
		safeDelayMicroseconds(RegisterDelayMicroSeconds);
		C64Control::ClearFlashWrite();
		C64Control::ToggleDotClock();

		//	C64Control::UpdateLatch();
			// Will clear flash write a little before the data output, this might generate a momentary logic contention state
			// TODO: See if both the write and the latch out can be cleared at the same time
		C64Control::ClearDataLatchOut();
		C64Control::UpdateLatch();
		C64Control::ToggleDotClock();
	}
}


void SendChipCommandErase(void)
{
	// Write some data to the flash, using the erase command sequence
	switch (flashChipType)
	{
	case M29F160:
		SendChipCommand(0xaaa, 0xaa);
		SendChipCommand(0x555, 0x55);
		SendChipCommand(0xaaa, 0x80);
		SendChipCommand(0xaaa, 0xaa);
		SendChipCommand(0x555, 0x55);
		SendChipCommand(0xaaa, 0x10);
		break;

	case M29F040:
		SendChipCommand(0x555, 0xaa);
		SendChipCommand(0x2aa, 0x55);
		SendChipCommand(0x555, 0x80);
		SendChipCommand(0x555, 0xaa);
		SendChipCommand(0x2aa, 0x55);
		SendChipCommand(0x555, 0x10);
		break;
	}
}

void SendChipCommandBlockErase(void)
{
	// Block erase commands
	// The actual block (sector in some datasheets) to erase usually comes from the bank register(s), from the upper address bits
	switch (flashChipType)
	{
	case M29F160:
		SendChipCommand(0xaaa, 0xaa);
		SendChipCommand(0x555, 0x55);
		SendChipCommand(0xaaa, 0x80);
		SendChipCommand(0xaaa, 0xaa);
		SendChipCommand(0x555, 0x55);
		SendChipCommand(0xba, 0x30);
		break;
	case M29F040:
		SendChipCommand(0x555, 0xaa);
		SendChipCommand(0x2aa, 0x55);
		SendChipCommand(0x555, 0x80);
		SendChipCommand(0x555, 0xaa);
		SendChipCommand(0x2aa, 0x55);
		SendChipCommand(0xba, 0x30);
		break;
	}
}

void SendChipCommandProgram(void)
{
	switch (flashChipType)
	{
	case M29F160:
		SendChipCommand(0xaaa, 0xaa);
		SendChipCommand(0x555, 0x55);
		SendChipCommand(0xaaa, 0xa0);
		break;
	case M29F040:
		SendChipCommand(0x555, 0xaa);
		SendChipCommand(0x2aa, 0x55);
		SendChipCommand(0x555, 0xa0);
		break;
	}
}
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

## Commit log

2025-05-28 Changed edge connector pads
2025-05-29 V1.0 PCBWay W382513ASJ99
    [Bill Of Materials C64MegaCart.csv, C64MegaCart - PNP.csv]
2025-06-24 Proj PCB
2025-06-25 Adding TE Connectivity 5530843-4 cartridge connector
2025-06-25 Adding Pi connector
2025-06-25 Raspberry Pi header on the bottom!
2025-06-26 Add debug header for the cartridge, large holes again
    Add power socket, LED, capacitors
    Add four indicator LEDs connected to the last latch
2025-06-26 Tidy the PCB stackup
2025-06-26 V1.0 build
    [Bill Of Materials CartTool - Routed.csv, Bill Of Materials CartTool - Routed.xlsx, CartTool - Routed - PNP.csv]
2025-06-26 Adjust top/front silkscreen position
2025-07-15 Enable the LED when the write is completed
2025-07-16 Reduce latch operations and skip erased bytes
    [main.cpp]
2025-07-17 Central mounting hole, for cart case
2025-07-17 C64MegaCart V2.0 assembly files
    [Bill Of Materials C64MegaCartV2.csv, Bill Of Materials C64MegaCartV2.xlsx, C64MegaCartV2 - PNP.csv]
2025-08-03 RaspberryPi5 testing
2025-08-07 Removed from simulation parts without models, added debug buttons.
2025-08-10 C64MegaCartV3: Specifically apply net to all edge connectors
2025-08-10 CartTool V2: Remove power plug
2025-08-10 CartTool V2: Add stock codes for resistors and LEDs
2025-08-10 CartTool V2: Move the Pi connector to the bottom left, so the USB stacked plugs do not hit the PCB
    CartTool V2: Push button switch to ground
2025-08-10 Add 3M connector for Pi
2025-08-10 Moved the cartridge slot to the middle
2025-08-10 CartToolV2 build
    [Bill Of Materials CartToolV2 Routed.csv, CartToolV2 Routed - BOM.xlsx, CartToolV2 Routed - PNP.csv]
2025-08-10 Button 3D model
2025-09-08 Tested working: CartTool V2: Level convertors can be replaced with on-board circuitry
    Erase/write/read cycle tested working
    LEDs work
    Button read works
    [main.cpp]
2025-09-09 Wait for button
2025-10-01 56.42mm wide and 6mm internal peg
2025-10-01 C64MegaCart V4.0 build
    [Bill Of Materials C64MegaCartV4 - Routed.xlsx, C64MegaCartV4 - Routed_Base Design - PNP.csv]
2025-11-02 Correcting docs typos and making different LEDs show erase/write/read status
    [main.cpp]
2025-11-08 Silkscreen and holes to vias
2025-11-08 Done: Move to mounting hole layer Done: Make unplated
2025-11-08 Above the edge connector, make narrower, 4.0 was too narrow.
2025-11-08 Tweak bottom edge connector ledge
2025-11-23 C64MegaCart V4.2
    [Bill Of Materials C64MegaCartV4.2 routed.csv, Bill Of Materials C64MegaCartV4.2 routed.xlsx, C64MegaCartV4.2 routed_Base Design PNP.csv]
2026-01-18 Case model
2026-01-18 Adding case bottom post PCB hole locator
    [C64MegaCartNormalCase.FCStd]
2026-01-18 V4.2 move hole up half the pillar edge width... >> V4.3
2026-01-18 MegaCart V4.3 and matching case
    [Bill Of Materials C64MegaCartV4.3 - BOM.xlsx, Bill Of Materials C64MegaCartV4.3.csv, C64MegaCartNormalCase-Assemblybottom001.step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]
2026-02-22 Updating links for the new PCB and case
2026-02-24 8MB V5.1
    [Bill Of Materials C64MegaCart8MBV5.1.csv, Bill Of Materials C64MegaCart8MBV5.1.xlsx, C64MegaCart8MBV5.1_Base Design.csv]
2026-04-06 Cart tool with five slots
    Adding bus isolation for cartridge slot
2026-04-06 Cart tool five slot layout and shared signal fixes
2026-04-06 Five slot cart tool design
    [Bill Of Materials CartToolFiveSlot - Routed.csv, Bill Of Materials CartToolFiveSlot - Routed.csv.xlsx, CartToolFiveSlot - Routed_Base Design.csv]
2026-05-10 Connecting the relay
2026-05-10 Resistor larger footprint and holes
2026-05-10 CartToolV3 with relay
    [Bill Of Materials CartToolV3 routed.csv, Bill Of Materials CartToolV3 routed.csv.xlsx, CartToolV3 routed_Base Design.csv]
2026-05-15 Added protection diode
2026-06-26 Add power relay
2026-06-26 Relay code
2026-06-26 Adjust board layout
2026-07-25 Adding CartGND and power wire/net class to CartVCC and CartGND
2026-07-25 Five slot design improvements
    [Bill Of Materials CartToolFiveSlot - Routed.csv, Bill Of Materials CartToolFiveSlot - Routed.csv.xlsx, CartToolFiveSlot - Routed_Base Design.csv]
2026-08-22 Starting to add multiple slot support
2026-08-22 Five slot updates
    o erase and write **five** 2 megabyte carts in parallel took... 97 seconds
    For one cart it took... 61 seconds
2026-08-23 Make sur IO is reset before serial EEPROM dump
    [main.cpp]
2026-08-25 Single slot tool power ground relay needs adding, like the five slot version.
    Five slot resistor placement updated
2026-09-24 Adding mounting holes and placement keep areas.
    [Bill Of Materials CartToolFiveSlot routed.csv, Bill Of Materials CartToolFiveSlot routed.csv.xlsx, Bill Of Materials CartToolV3 routed.csv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]
2026-10-30 Add --activeslot, mostly useful for testing a single slot on the multi-slot programmer
